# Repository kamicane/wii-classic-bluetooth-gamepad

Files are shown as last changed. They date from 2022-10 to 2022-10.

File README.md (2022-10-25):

# Wii Classic Bluetooth gamepad

Bluetooth conversion of the Wii Classic gamepad using an Esp32.
Uses [NintendoExtensionCtrl](https://github.com/dmadison/NintendoExtensionCtrl) to read the controller and [ESP32-BLE-Gamepad](https://github.com/lemmingDev/ESP32-BLE-Gamepad) to do Bluetooth things.

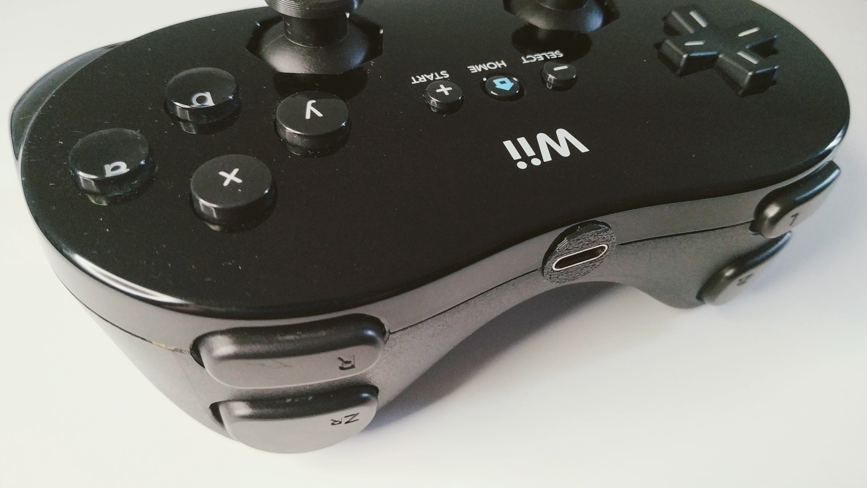
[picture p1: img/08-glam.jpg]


## Features

- Analog joysticks with [scaled radial deadzone](https://github.com/Minimuino/thumbstick-deadzones)
- auto sleep
- manual sleep
- analog sticks calibration
- dual core: reporting to bluetooth takes place in one core, and reading inputs in another. This ensures the lowest possible latency

## Usage

- Wake from sleep: home button
- Force sleep: keep select pressed for 5 seconds
- Auto sleep: no inputs for 5 minutes
- Calibration mode: keep X pressed while it wakes from sleep

## Calibration mode

- Press home to wake the controller from sleep, keeping X pressed for a few seconds
- Keep the analog sticks in their center position, then press select
- Move the analog sticks to their full range, then press select
- The Esp32 saves the calibration data to the internal eeprom then reboots

## Issues

- No external leds: I should add some to see what's going on (connected / disconnected / calibration mode, low battery, etc)
- Reading the classic controller through i2c is "slow". I measured between 3 and 5 ms.

## Parts used

- Platformio: to build and flash the code
- Esp32 board: Lolin32 lite because it's cheap on aliexpress and has an integrated lipo charger
- Lipo battery: I used an 802535 (600mah) because it fits nicely
- USB C connector with breakout board: the shorter & narrower the better. I used a fairly large one and I had to trim the controller pcb a tiny bit to make it fit
- Stuff to trim the shell: craft files, flush cutters, (low) power tools
- A 3d printer to print the usb gasket
- Superglue to glue the USB connector to the gasket, and the gasket to the shell
- 30awg solid core wire, solder, flux
- Hot air or hot plate to remove the battery connector from the Esp32
- Double sided tape to secure the Esp32 and the battery

## How I built it

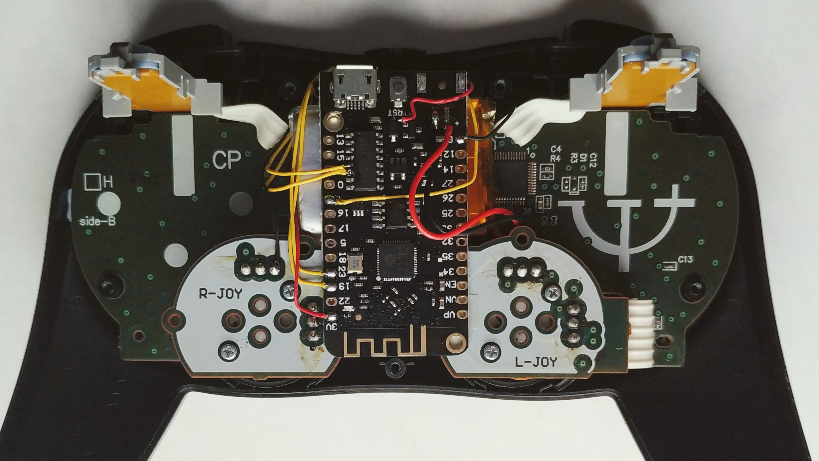
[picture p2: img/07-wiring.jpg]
assembly


- Disassembled the controller, trimmed the shell (look in [/img](/img))
- Desoldered the battery connector from the Esp32 since it's too tall otherwise
- Taped the Esp32 to the bottom pcb (the one with the analogs) carefully and making sure it fit within the shell. Then I trimmed more
- Soldered i2c pins, 3v and ground to the relative Esp32 pins
- Soldered the top pin of the home switch to the Esp32. This needs to be an RTCIO pin as it will be used to wake the Esp32 from sleep
- Soldered the usb connector to the Esp32. I had to use the legs of the CH340C (pin 5 D+, pin 6 D-) and a diode (5v), as the Esp32 does not expose pads for usb connection
- Soldered the battery to the battery pads
- Taped the battery to the back of the Esp32, making sure everything fit, and making sure I could still screw the pcb to the front shell. Then I trimmed more

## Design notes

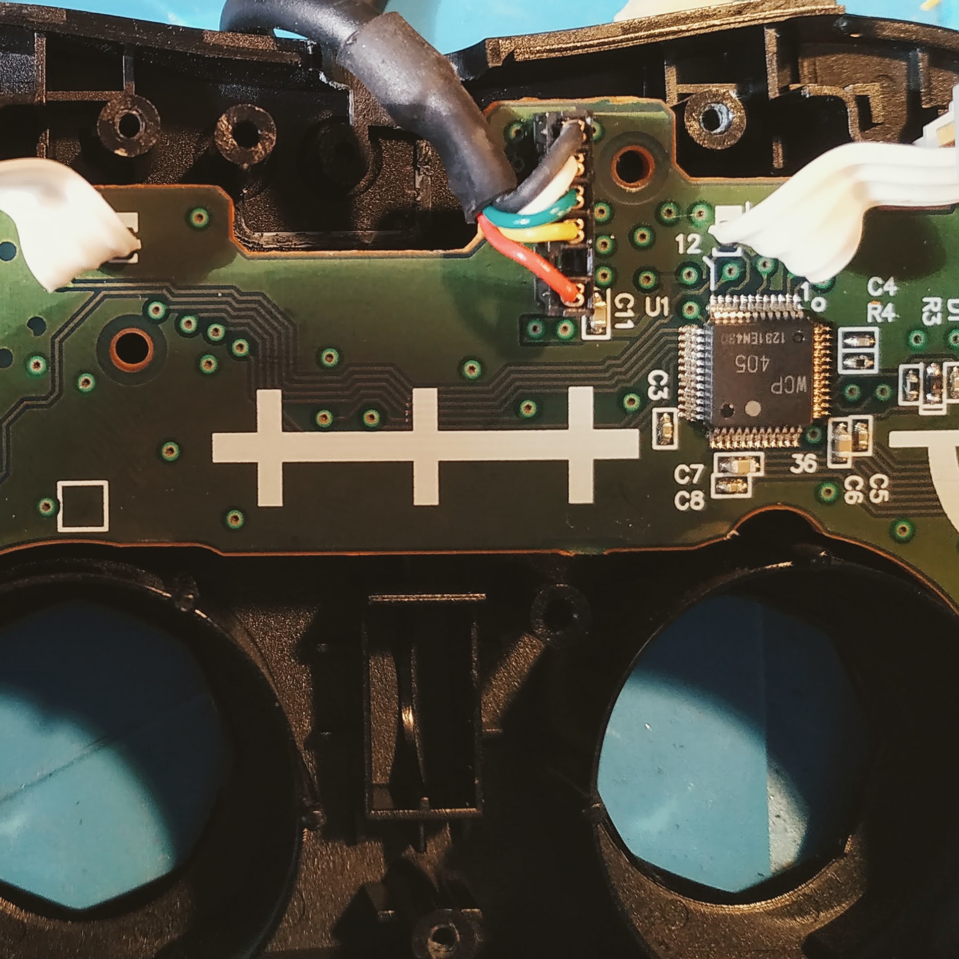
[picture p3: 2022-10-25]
img/01-connector.jpg

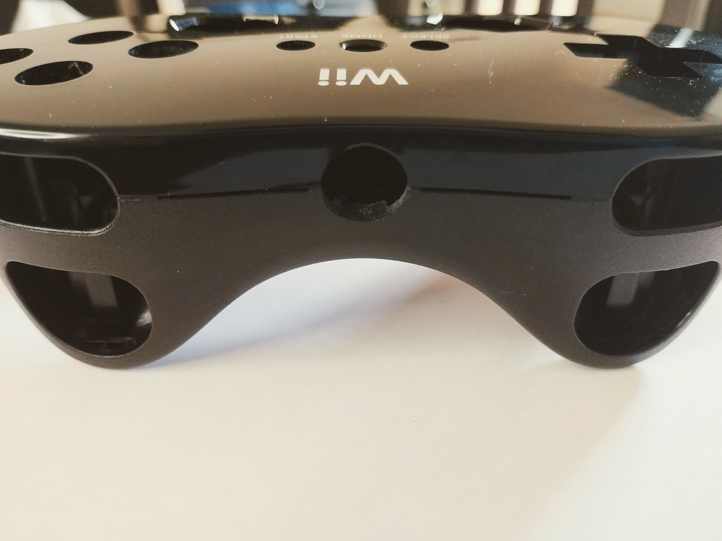
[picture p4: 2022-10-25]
img/04-nice-hole.jpg

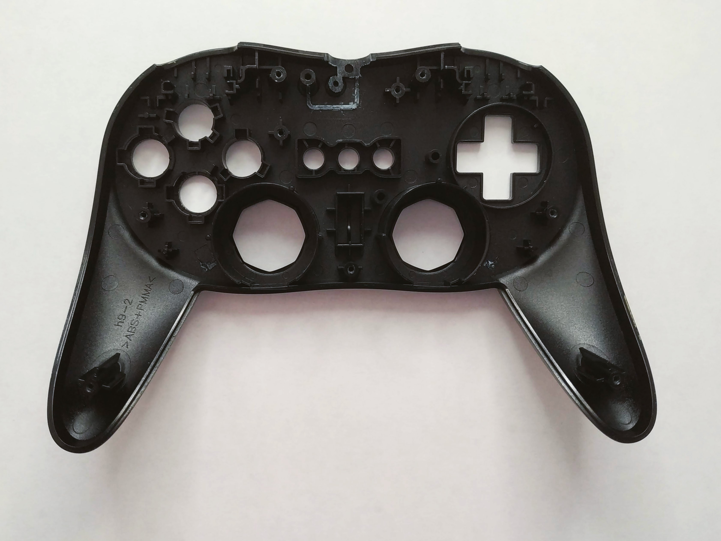
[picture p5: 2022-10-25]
img/02-trim-front.jpg

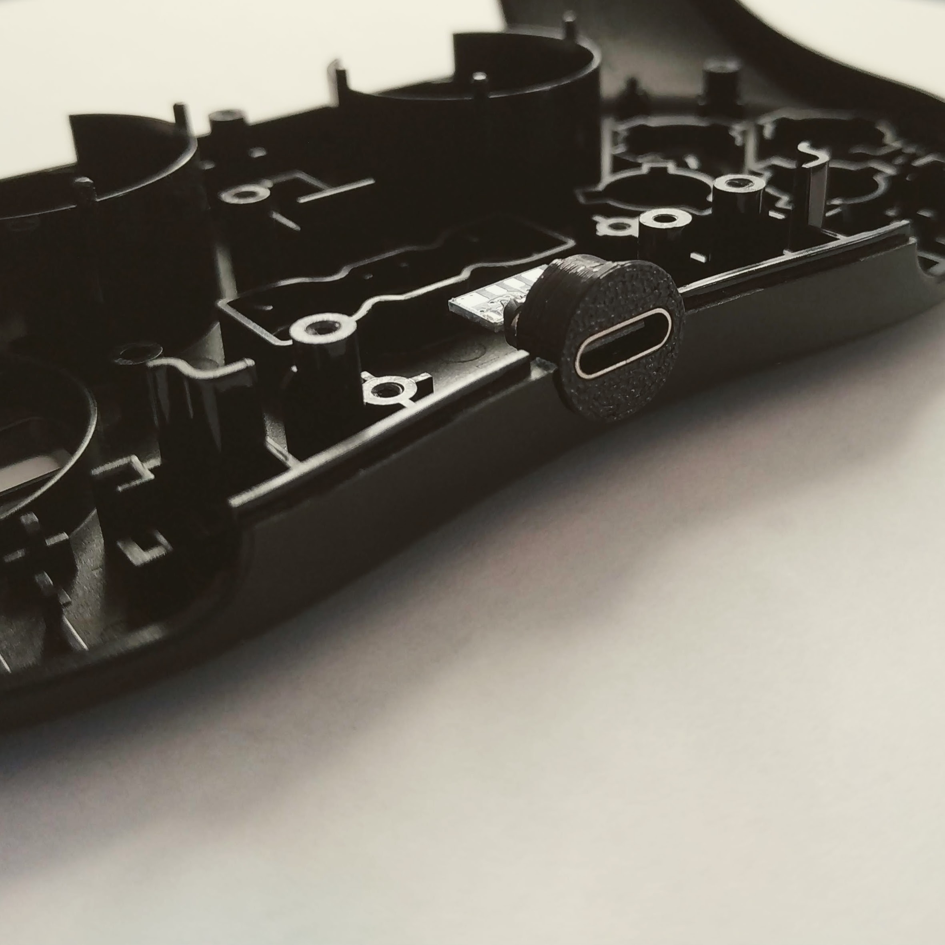
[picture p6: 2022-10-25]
img/05-usb-glued.jpg

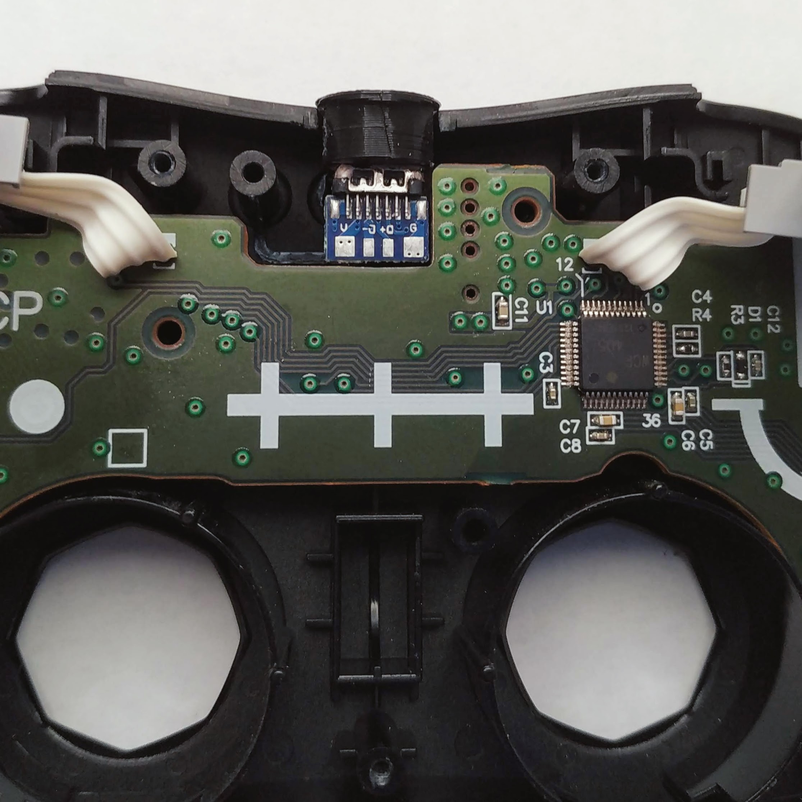
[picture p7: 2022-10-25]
img/06-usb-fit.jpg

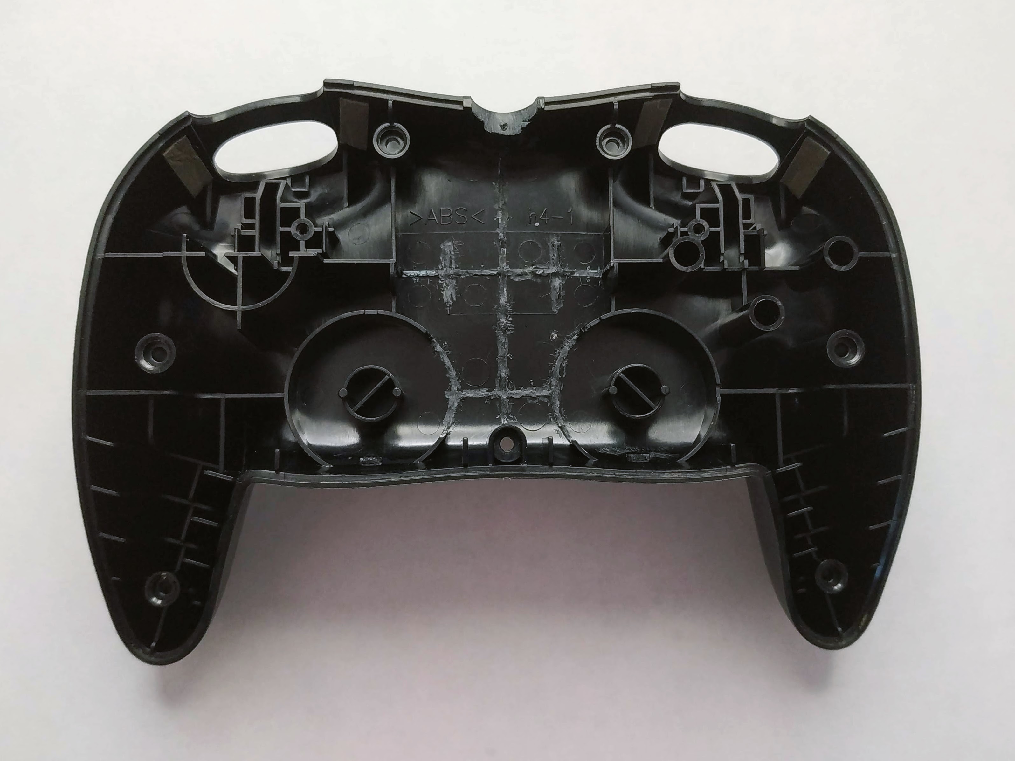
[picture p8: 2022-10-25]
img/03-trim-back.jpg

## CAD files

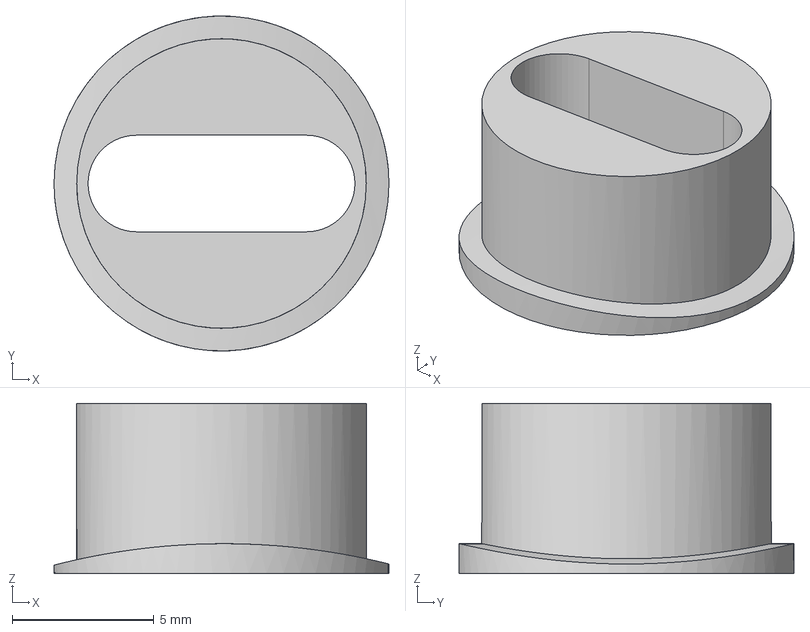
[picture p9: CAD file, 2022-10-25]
3d/WiiClassic-USBC-Gasket.step
11.8 x 11.8 x 6.00 mm

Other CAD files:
3d/WiiClassic-USBC-Gasket.stl

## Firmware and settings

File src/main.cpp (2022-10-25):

#include <Arduino.h>
#include <TickTwo.h>
#include <NintendoExtensionCtrl.h>

#include <BluJoy.h>

// Green → SDA -> 19
// Red → 3v3
// White → GND
// Yellow → SCL -> 23

/* config */

// #define JOY_DEBUG 1

const uint REPORT_RATE = 1000; // micros, 1ms
const uint CLASSIC_POLL_RATE = 1000; // micros, 1ms

const float DEADZONE = 0.20;

const uint SLEEP_TIMEOUT = 5; // minutes
const uint SLEEP_BUTTON_TIMEOUT = 5; // seconds

// pins

const byte LED_PIN = 22;
const byte HOME_PIN = 4; // manually wired for sleep wakeup

/* end config */

TaskHandle_t core0_handle;

BluJoy joy("Wii Classic Gamepad", "Nintendo", DEADZONE);

bool IS_BLE_CONNECTED = false;
bool IS_CLASSIC_CONNECTED = false;

byte LED_STATE = HIGH;

bool CALIBRATION_MODE = false;

ClassicController classic;

void report ();
void report_calibrate ();
void toggle_led ();
void deep_sleep ();
void ble_conn_check ();
void i2c_conn_check ();
void classic_poll();

#ifdef JOY_DEBUG
void debug_common ();
TickTwo debug_interval(debug_common, 1000, 0); // 1 second
#endif

TickTwo report_interval(report, REPORT_RATE, 0, MICROS_MICROS);
TickTwo classic_poll_interval(classic_poll, CLASSIC_POLL_RATE, 0, MICROS_MICROS);
TickTwo ble_conn_check_interval(ble_conn_check, 1000, 0); // 1 second
TickTwo i2c_conn_check_interval(i2c_conn_check, 1000, 0); // 1 second
TickTwo calibrate_interval(report_calibrate, REPORT_RATE, 0, MICROS_MICROS);
TickTwo nc_led_interval(toggle_led, 1000, 0); // 1 second
TickTwo sleep_timeout(deep_sleep, SLEEP_TIMEOUT * 60000, 0);
TickTwo button_sleep_timeout(deep_sleep, SLEEP_BUTTON_TIMEOUT * 1000, 1);

void stop_all_timers () {
  report_interval.stop();
  i2c_conn_check_interval.stop();
  ble_conn_check_interval.stop();
  calibrate_interval.stop();
  nc_led_interval.stop();
  sleep_timeout.stop();
  button_sleep_timeout.stop();

  classic_poll_interval.stop();
}

void update_core1_timers () {
  report_interval.update();
  i2c_conn_check_interval.update();
  ble_conn_check_interval.update();
  calibrate_interval.update();
  nc_led_interval.update();
  sleep_timeout.update();
  button_sleep_timeout.update();

  #ifdef JOY_DEBUG
  debug_interval.update();
  #endif
}

void update_core0_timers () {
  classic_poll_interval.update();
}

void read_dpad () {
  joy.set_dpad_state(!classic.dpadUp(), !classic.dpadRight(), !classic.dpadDown(), !classic.dpadLeft());
}

void read_buttons () {
  joy.set_button_state(BluJoy::BUTTON_A, !classic.buttonB());
  joy.set_button_state(BluJoy::BUTTON_B, !classic.buttonA());
  joy.set_button_state(BluJoy::BUTTON_X, !classic.buttonY());
  joy.set_button_state(BluJoy::BUTTON_Y, !classic.buttonX());

  joy.set_button_state(BluJoy::BUTTON_START, !classic.buttonPlus());
  joy.set_button_state(BluJoy::BUTTON_SELECT, !classic.buttonMinus());
  joy.set_button_state(BluJoy::BUTTON_HOME, !classic.buttonHome());

  joy.set_button_state(BluJoy::BUTTON_LB, !classic.buttonL());
  joy.set_button_state(BluJoy::BUTTON_RB, !classic.buttonR());
}

float map_axis_value (byte classic_axis_value, bool invert = false) {
  if (invert) return BluJoy::map_range(classic_axis_value, 0.0, 255.0, 1.0, -1.0);
  return BluJoy::map_range(classic_axis_value, 0.0, 255.0, -1.0, 1.0);
}

void read_axes () {
  joy.set_axis_state(BluJoy::AXIS_LX, map_axis_value(classic.leftJoyX()));
  joy.set_axis_state(BluJoy::AXIS_LY, map_axis_value(classic.leftJoyY(), true));
  joy.set_axis_state(BluJoy::AXIS_RX, map_axis_value(classic.rightJoyX()));
  joy.set_axis_state(BluJoy::AXIS_RY, map_axis_value(classic.rightJoyY(), true));
  joy.set_axis_state(BluJoy::AXIS_LT, classic.buttonZL() ? 1.0 : -1.0);
  joy.set_axis_state(BluJoy::AXIS_RT, classic.buttonZR() ? 1.0 : -1.0);
}

#ifdef JOY_DEBUG
uint classic_runs = 0;
unsigned long classic_timer = 0;
uint32_t report_runs = 0;
#endif

void core0_loop (void *p) {
  for(;;) {
    update_core0_timers();
  }
}

void loop () {
  update_core1_timers();
}

void classic_poll () {
  if (!IS_CLASSIC_CONNECTED) return;

  #ifdef JOY_DEBUG
  classic_runs++;
  unsigned long start = micros();
  #endif
  classic.update();

  read_dpad();
  read_buttons();
  read_axes();
  #ifdef JOY_DEBUG
  unsigned long end = micros();
  classic_timer += end - start;
  #endif
}

void setup () {
  #ifdef JOY_DEBUG
  Serial.begin(115200);
  Serial.print("setup\n");

  debug_interval.start();
  #endif

  xTaskCreatePinnedToCore(
    core0_loop, /* Function to implement the task */
    "core0_loop", /* Name of the task */
    10000,  /* Stack size in words */
    NULL,  /* Task input parameter */
    0,  /* Priority of the task */
    &core0_handle,  /* Task handle. */
    0 /* Core where the task should run */
  );

  joy.prefs_init();
  classic.begin();

  pinMode(LED_PIN, OUTPUT);

  esp_sleep_enable_ext0_wakeup((gpio_num_t)HOME_PIN, LOW);

  i2c_conn_check_interval.start();
}

void toggle_led () {
  digitalWrite(LED_PIN, LED_STATE = !LED_STATE);
}

void deep_sleep () {
  stop_all_timers();

  #ifdef JOY_DEBUG
  Serial.print("entering sleep mode\n");
  #endif

  if (joy.is_connected()) {
    joy.raise_inputs();
    joy.report();
  }

  // delay needed otherwise buttons remain pressed briefly on disconnect (?)
  delay(120);
  esp_deep_sleep_start();
}

void i2c_conn_check () {
  if (!classic.connect()) {
    IS_CLASSIC_CONNECTED = false;
    return;
  }

  IS_CLASSIC_CONNECTED = true;
  i2c_conn_check_interval.stop();

  classic.update();

  CALIBRATION_MODE = classic.buttonY();

  if (CALIBRATION_MODE) {

    #ifdef JOY_DEBUG
    Serial.print("calibration mode\n");
    Serial.print("put all axes in neutral position then press select\n");
    #endif

    calibrate_interval.start();

  } else {

    joy.read_calibration_data();

    #ifdef JOY_DEBUG
    for (byte axis = 0; axis < BluJoy::AXIS_COUNT; axis++) {
      Serial.print(String(joy.axis_names[axis]) +
        " min: " + String(joy.get_axis_min(axis)) +
        ", mid: " + String(joy.get_axis_mid(axis)) +
        ", max: " + String(joy.get_axis_max(axis)) + "\n"
      );
    }
    #endif

    joy.connect();

    classic_poll_interval.start();
    report_interval.start();
    ble_conn_check_interval.start();
    nc_led_interval.start();
    sleep_timeout.start();
  }
}

float axes_min[4] = { 0.0, 0.0, 0.0, 0.0 };
float axes_max[4] = { 0.0, 0.0, 0.0, 0.0 };

byte CALIBRATION_STATE = 0;
byte special_btn_state_old = HIGH;

void report_calibrate () {
  classic_poll();

  byte special_btn_state_new = joy.get_button_state(BluJoy::BUTTON_START);
  bool special_btn_pressed = special_btn_state_old == HIGH && special_btn_state_new == LOW;
  special_btn_state_old = special_btn_state_new;

  if (CALIBRATION_STATE == 1) {
    for (byte axis = 0; axis < 4; axis++) { // first 4 axes
      float state = joy.get_axis_state_raw(axis);
      if (state < axes_min[axis]) {
        axes_min[axis] = state;
        joy.set_axis_min(axis, state);
      } else if (state > axes_max[axis]) {
        axes_max[axis] = state;
        joy.set_axis_max(axis, state);
      }
    }
  } else if (CALIBRATION_STATE == 0) {
    for (byte axis = 0; axis < 4; axis++) { // first 4 axes
      joy.set_axis_mid(axis, joy.get_axis_state_raw(axis));
    }
  }

  if (special_btn_pressed) {
    if (CALIBRATION_STATE == 0) {
      CALIBRATION_STATE = 1;
      #ifdef JOY_DEBUG
      Serial.print("now move all axes full range then press select\n");
      #endif
    } else {
      joy.write_calibration_data();

      #ifdef JOY_DEBUG
      for (byte axis = 0; axis < BluJoy::AXIS_COUNT; axis++) {
        Serial.print(
          String(joy.axis_names[axis]) +
          " min: " + String(joy.get_axis_min(axis)) +
          ", mid: " + String(joy.get_axis_mid(axis)) +
          ", max: " + String(joy.get_axis_max(axis)) + "\n"
        );
      }

      Serial.print("calibration done\n");
      #endif

      calibrate_interval.stop();

      delay(500);
      ESP.restart();
    }
  }
}

void ble_conn_check () {
  if (!joy.is_connected()) { // Bluetooth not connected
    if (IS_BLE_CONNECTED) { // was previously connected (is disconnected)
      #ifdef JOY_DEBUG
      Serial.print("bluetooth disconnected\n");
      #endif
      digitalWrite(LED_PIN, HIGH);
      nc_led_interval.start();
      IS_BLE_CONNECTED = false;
    }
    return;
  } else { // Bluetooth connected
    if (!IS_BLE_CONNECTED) {
      #ifdef JOY_DEBUG
      Serial.print("bluetooth connected\n");
      #endif

      joy.raise_inputs();

      nc_led_interval.stop();
      digitalWrite(LED_PIN, LED_STATE = LOW);

      IS_BLE_CONNECTED = true;
    }
  }
}

void report () {
  #ifdef JOY_DEBUG
  report_runs++;
  #endif

  // FORCE SLEEP

  if (joy.get_button_state(BluJoy::BUTTON_SELECT) == LOW) {
    if (button_sleep_timeout.state() != RUNNING) button_sleep_timeout.start();
  } else {
    button_sleep_timeout.stop();
  }

  if (joy.is_any_pressed()) {
    sleep_timeout.stop();
    sleep_timeout.start();
  }

  joy.report();
}

#ifdef JOY_DEBUG
void debug_common () {
  for (byte btn = 0; btn < BluJoy::BUTTON_COUNT; btn++) {
    const std::string spacer = (btn < BluJoy::BUTTON_COUNT - 1) ? ", " : "";
    Serial.print(
      String(joy.button_names[btn]) +
      ": " + String(joy.get_button_state(btn)) + spacer.c_str()
    );
  }
  Serial.print(" :: ");
  for (byte axis = 0; axis < BluJoy::AXIS_COUNT; axis++) {
    const std::string spacer = (axis < BluJoy::AXIS_COUNT - 1) ? ", " : "";
    Serial.print(
      String(joy.axis_names[axis]) +
      ": " + String(joy.get_axis_state(axis)) + "(" + String(joy.get_axis_state_raw(axis)) + ")" + spacer.c_str()
    );
  }
  Serial.print(":: DP: " + String(joy.get_dpad_state()) + "\n");
  if (classic_runs > 0) Serial.print("classic runs timer: " + String(classic_timer / classic_runs) + " :: ");
  Serial.print("report runs: " + String(report_runs) + " :: classic runs: " + String(classic_runs) + "\n");

  report_runs = 0;
  classic_runs = 0;
  classic_timer = 0;
}
#endif

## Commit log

2022-10-25 add 3d models
    [WiiClassic-USBC-Gasket.step, WiiClassic-USBC-Gasket.stl]
2022-10-25 add wiring to readme
